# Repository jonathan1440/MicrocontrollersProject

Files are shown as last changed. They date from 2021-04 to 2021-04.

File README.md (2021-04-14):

# MicrocontrollersProject
 Hands-free deodorant dispenser

## Parts List
- 3x 1µF capacitors
- 1x 10µF capacitor
- 1x 2x3 header
- 1x 1x3 header
- 1x 1x4 header
- 1x transistor
- 1x Q3 crystal
- 2x 22 Ohm resistors
- 3x 10k Ohm resistors
- 2x buttons
- 1x 3 prong switch
- 1x AT90USB162 chip
- 1x USB micro B port
- 1x servo
- 1x Sharp GP2D02 IR sensor

## User Instructions
Flip the switch to on. Position yourself directly in front of the sensor. To tirgger the servo, move within 8-13 cm of the sensor. To release the servo, don't be within 8-13cm of the sensor.

## Code Overview
Pinout:
- PC7 - "on/off" switch
- PB5 - sensor output
- PB6 - sensor Vin
- PB7 - servo

GetDist() reads the data value from the IR sensor. The biggest roadblock was figguring out that the IR sensor was open drain. Otherwise the function just follows the Sharp GP2302 datasheet.

The main() function configures the pinout and initializes the PWM timer (clear OC0A at match, fast PWM mode, top defaults to 0xFF, prescaler = 64). The while loop waits until the switch is positioned at "on," and then moves the servo to the appropriate position if the user is within range or out of range. If the user is not detected by the sensor, the servo is turned off.

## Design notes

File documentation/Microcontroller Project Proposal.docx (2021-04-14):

Microcontroller Project

Description:
Dispense an aerosol can when the user is within a certain distance of an IR sensor.

Requirements:
Get distance from user to sensor, if distance within certain range and device switched on, trigger server to dispense the aerosol can.

1. AT90USB162 – Atmel AVR microcontroller
2. Sensor interface
3. ISR
4. Custom PCB
5. All code will be written myself
6. Will take ~25 hours to complete:
  a. 5 hours to design PCB
  b. 5 hours to assemble PCB
  c. 15 hours to develop software
7. The system will be evaluated by the range of light levels in which it is operable.

Sprint timeline:

  a. 5 hours to design PCB
  b. 5 hours to assemble PCB
  c. 15 hours to develop software

System testing:
The system will be tested 5 times in each of the following light levels:

1. No light
2. Some light
3. Medium light
4. High light
5. Direct light

It will be considered a success if it can successfully operate in 90% of cases in medium and high light.

Final deliverables:

1. Parts list
2. PCB schematic
3. Code
4. Appropriate documentation
5. User instructions

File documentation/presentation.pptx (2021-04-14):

## Hands-free Deodorant

CPHE 380 Final Project
Jonathan Ziesmer

## Description

Aerosolized deodorant is dispensed by a servo when the user is within range of an IR sensor.

## Requirements:

1. AT90USB162 Atmel AVR microcontroller
2. Sensor interface
3. ISR
4. Custom PCB
5. All code is custom written
6. >20 hours to complete
7. Pass testing

## Sprint overviews

1. 5 hours to design PCB
2. 5 hours to assemble PCB
3. 15 hours to develop software

## Testing summary

Light level | Test 1 | Test 2 | Test 3 | Test 4 | Test 5 | Pass %
No light | Fail | Pass | Pass | Pass | Pass | 80%
Low light | Pass | Pass | Pass | Fail | Pass | 80%
Medium light | Pass | Pass | Pass | Pass | Pass | 100%
High light | Pass | Pass | Pass | Fail | Pass | 80%
Direct light | Fail | Pass | Fail | Pass | Pass | 60%

The system is considered a success since it passed 90% of tests in medium and high light.

## Final Deliverables

- Board design and parts list
- Code
- Documentation
- User instructions
github.com/jonathan1440/MicrocontrollersProject

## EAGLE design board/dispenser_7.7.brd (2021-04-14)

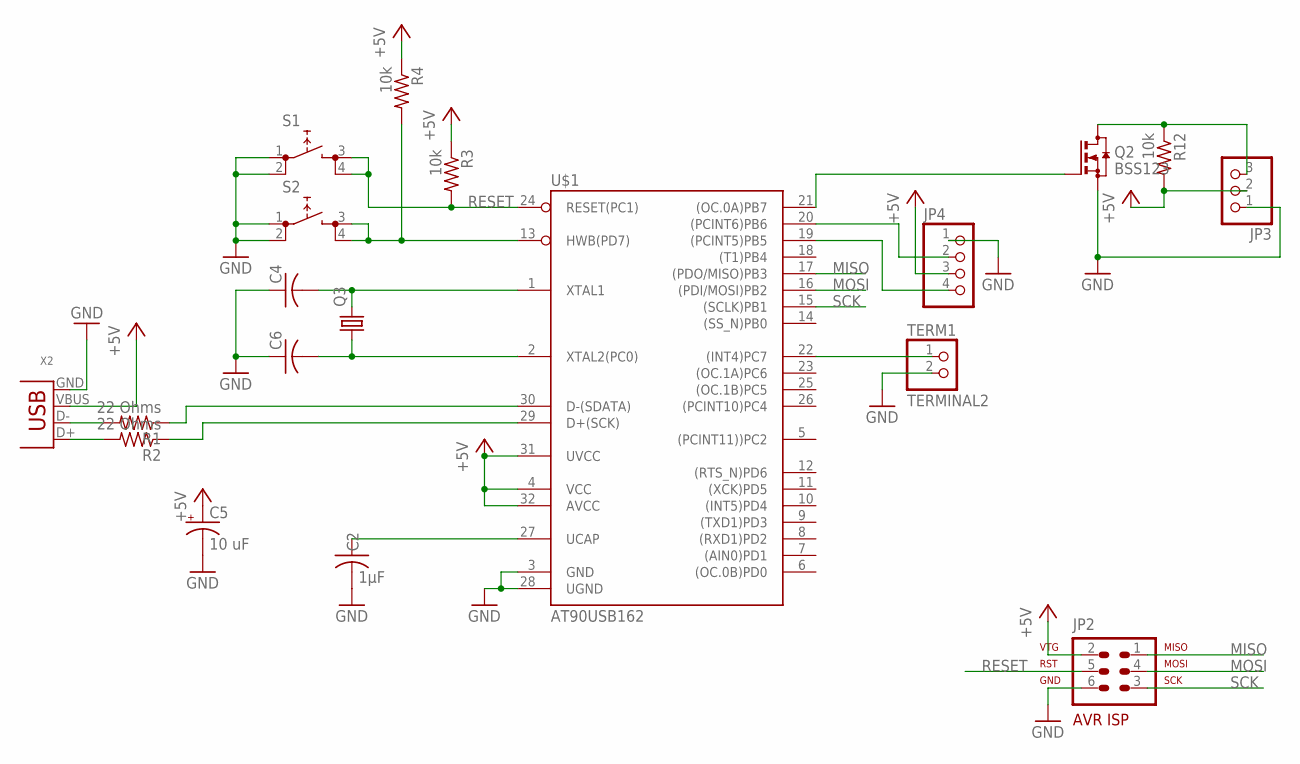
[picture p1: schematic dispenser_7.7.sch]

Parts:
C2: 1µF; C050-025X075
C4, C6: C-USC050-025X075; C050-025X075
C5: 10 uF; E2,5-5
JP2: AVR-ISP-6
JP3: PINHD-1X3; 1X03
JP4: PINHD-1X4; 1X04
Q2: BSS123; SOT23
Q3: CRYSTALHC49S; HC49/S
R1, R2: 22 Ohms; 0207/7
R3, R4, R12: 10k; 0207/7
S1, S2: PUSHBUTTON; TL1105SP
TERM1: TERMINAL2; TERM2
U$1: AT90USB162; TQFP32-08
X2: USB-MB-H

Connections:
+5V: C5.+, JP2.2, JP3.2, JP4.3, R3.1, R4.1, R12.2, U$1.4 (VCC), U$1.31 (UVCC), U$1.32 (AVCC), X2.VBUS
GND: C2.2, C4.1, C5.-, C6.1, JP2.6, JP3.1, JP4.1, Q2.2 (S), S1.1 (0), S1.2 (0), S2.1 (0), S2.2 (0), TERM1.2, U$1.3 (GND), U$1.28 (UGND), X2.GND
MISO: JP2.1, U$1.17 ((PDO/MISO)PB3)
MOSI: JP2.4, U$1.16 ((PDI/MOSI)PB2)
unnamed: JP4.4, U$1.19 ((PCINT5)PB5)
unnamed: JP4.2, U$1.20 ((PCINT6)PB6)
unnamed: C4.2, Q3.2, U$1.1 (XTAL1)
unnamed: Q2.1 (G), U$1.21 ((OC.0A)PB7)
unnamed: C6.2, Q3.1, U$1.2 (XTAL2(PC0))
unnamed: R2.1, U$1.29 (D+(SCK))
unnamed: TERM1.1, U$1.22 ((INT4)PC7)
unnamed: R2.2, X2.D+
unnamed: R1.2, X2.D-
unnamed: C2.1, U$1.27 (UCAP)
unnamed: R1.1, U$1.30 (D-(SDATA))
unnamed: R4.2, S2.3 (1), S2.4 (1), U$1.13 (HWB(PD7))
unnamed: JP3.3, Q2.3 (D), R12.1
RESET: JP2.5, R3.2, S1.3 (1), S1.4 (1), U$1.24 (RESET(PC1))
SCK: JP2.3, U$1.15 ((SCLK)PB1)

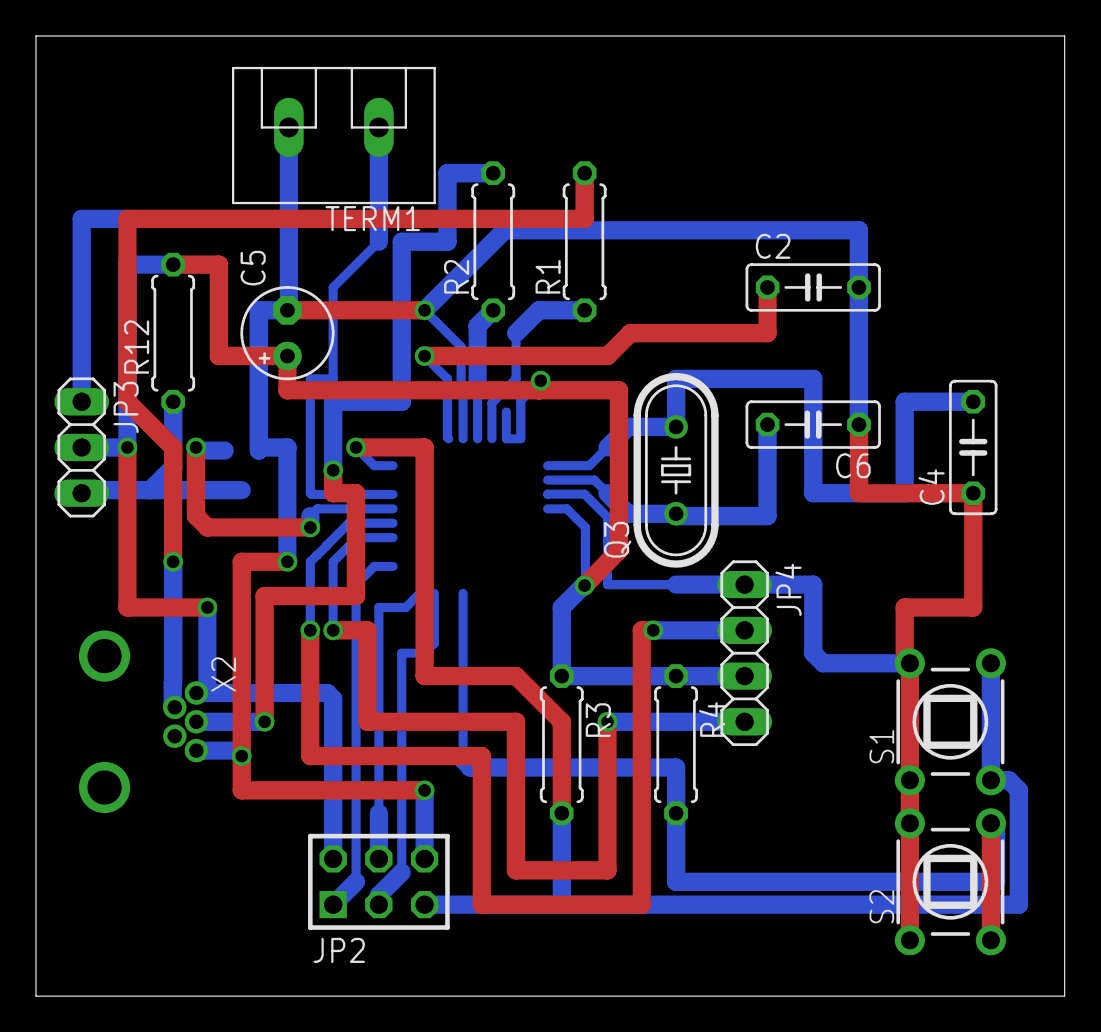
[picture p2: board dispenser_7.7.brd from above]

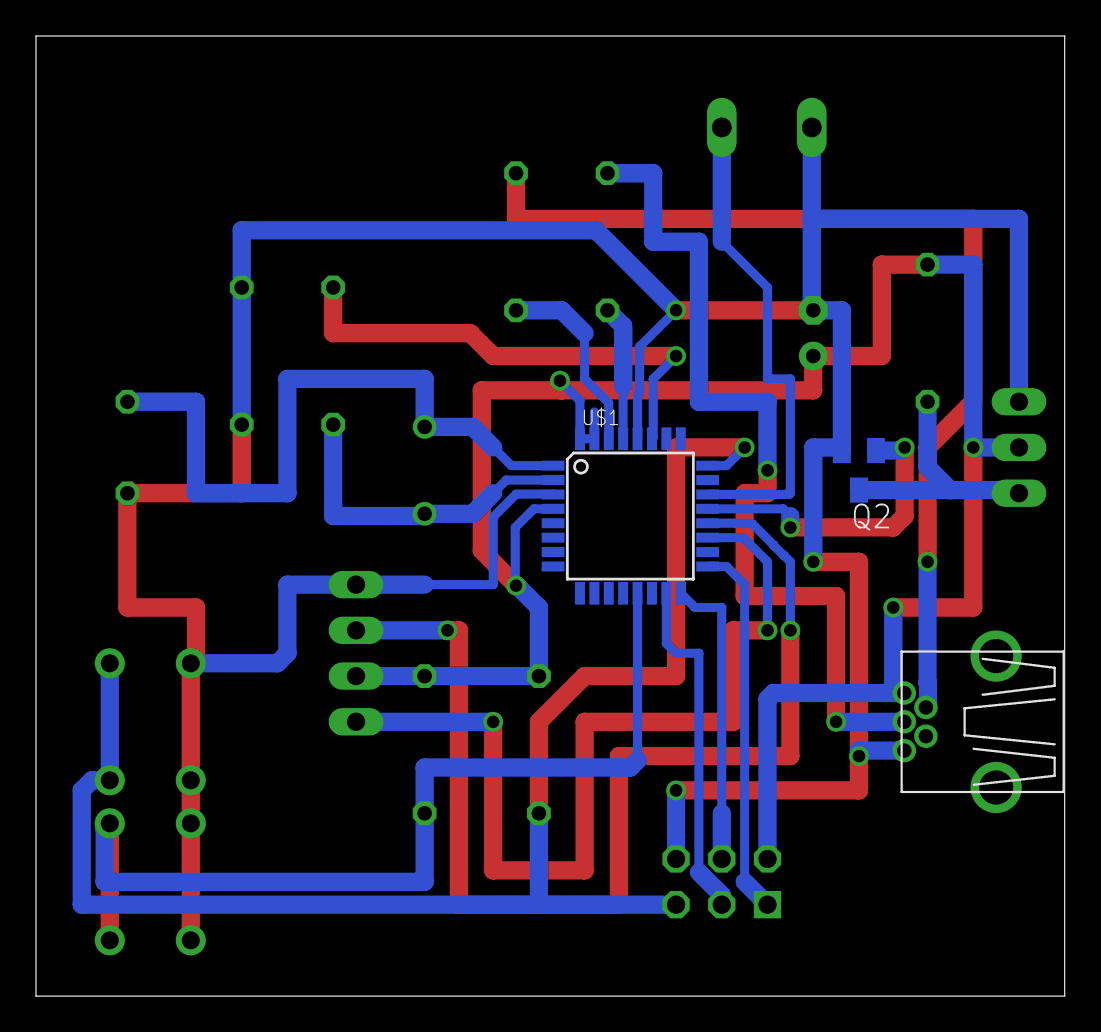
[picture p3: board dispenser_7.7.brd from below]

Board: 2 copper layers, 57.1 x 53.3 mm, 19 parts (2 on the bottom side), 19 nets.

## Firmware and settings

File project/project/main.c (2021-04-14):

/*
 * project.c
 *
 * Created: 12/14/2020 1:09:56 PM
 * Author : Jonathan Ziesmer
 */ 

#define F_CPU 1000000UL

#define MIN_RANGE 0xD2  // 8 cm or ~13 cm
#define MAX_RANGE 0xF0  // ~10.5 cm
#define OUT_RANGE 0xA6  // 21.5 cm

#include <avr/io.h>
#include <util/delay.h>
#include <stdio.h>
#include <avr/interrupt.h>


uint8_t GetDist(void)
{
	// PB6 - Vin to sensor
	// PB5 - Out of sensor
	
	DDRB |= (1<<DDB6);  // set PB6 low
	_delay_ms(20);
	while(!(PINB & 0x20)){;}  // wait for PB5 to go high
	DDRB &= ~(1<<DDB6);  // set PB6 high
	_delay_us(100);  // wait .1ms
	
	uint8_t counter = 0;
	uint8_t data = 0x00;
	while(counter < 8)
	{
		DDRB |= (1<<DDB6);  // set PB6 low
		_delay_us(100);  // wait .1ms
		uint8_t temp = (PINB & 0x20) >> 5;  // mask with PB5
		data = (data << 1) | temp;
		DDRB &= ~(1<<DDB6);  // set PB6 high
		_delay_us(100);  // wait .1ms
		counter ++;
	}
	
	_delay_ms(2);  // wait 1.5 or more to put sensor in sleep mode
	
	return data;
}


int main(void)
{
	// PC7 - "on/off" switch
	// PB6 - Sensor Vin
	// PB5 - Sensor output
	// PB7 - servo
	
	DDRC = (0<<DDC7);  // set PC7 to input	
	PORTC = (1<<PC7);  // set PC7 to pullup
	
	DDRB = (1<<DDB6) | (1<<DDB7);  // set PB6 & PB7 to output, set PB5 to input
	PORTB = (1<<PB7) | (0<<PB6);  // set PB7 high, PB6 low
	
	
	// timer PWM init
	TCCR0A = (1<<COM0A0) | (1<<COM0A1) | (1<<WGM01) | (1<<WGM00);  // clear OC0A at match, set timer to fast PWM, top defaults to 0xFF
	
	int moved = 1;
	
    while (1) 
    {
		while(!(PINC & 0x80)) {;}  // wait while PC7 not high
		
		uint8_t dist = GetDist();
		if(dist > MIN_RANGE && dist < MAX_RANGE)  // if user within range
		{
			OCR0A = 37;  // set servo position
			TCCR0B = (1<<CS01) | (1<<CS00);  // start timer PWM
			moved = 0;			
		}
		else if(dist < MIN_RANGE && dist > OUT_RANGE)  // if user moving in/out of range
		{
			OCR0A = 20;  // set servo position
			TCCR0B = (1<<CS01) | (1<<CS00);  // start timer PWM
			moved = 0;			
		}
		else{  // if user out of range
			TCCR0B = 0;  // stop timer
		}
		
		if(!moved)
		{
			_delay_ms(450);  // wait for servo to finish motion
			moved = 1;
		}
    }
}
